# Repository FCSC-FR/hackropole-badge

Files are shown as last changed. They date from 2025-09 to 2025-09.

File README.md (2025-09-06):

# Hackropole badge

<!--
SPDX-FileCopyrightText: 2025 Hackropole
SPDX-License-Identifier: CC-BY-4.0
-->

This repository contains the source files and build instructions for the
Hackropole badge.

See [./hardware/](./hardware/) for PCB source files, and production instructions.

See [./assembly/](./assembly/README.en.md) for PCB assembly instructions
(available [in French](./assembly/README.fr.md) and [in English](./assembly/README.en.md)).

See [./firmware-wled/](./firmware-wled/README.en.md) for firmware flashing and
configuration guide (available [in French](./firmware-wled/README.fr.md) and
[in English](./firmware-wled/README.en.md)).

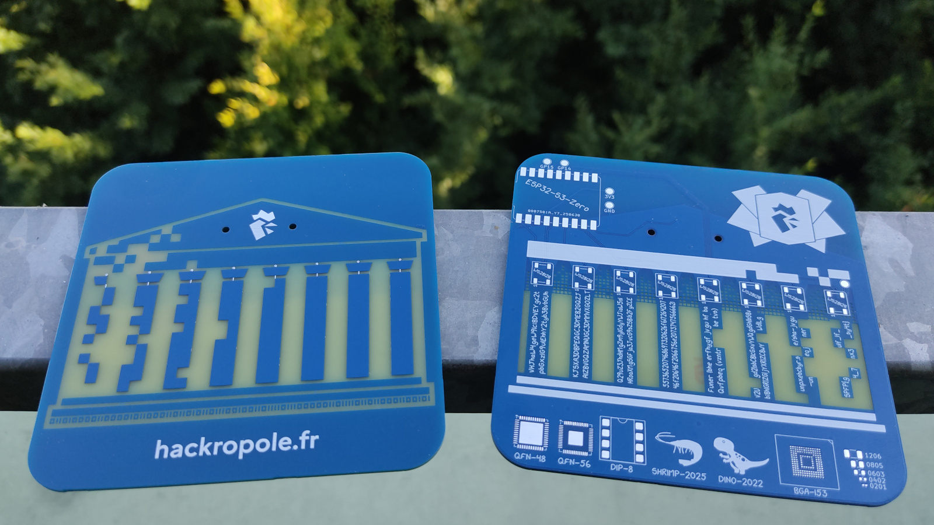
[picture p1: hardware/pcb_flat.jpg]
Pre-assembly badge


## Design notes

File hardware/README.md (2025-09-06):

# Hackropole badge

<!--
SPDX-FileCopyrightText: 2025 Hackropole
SPDX-License-Identifier: CC-BY-4.0
-->

Badge

This PCB was designed with Kicad 9.0.

## Sending the PCB to production

We recommend the following settings when sending the design files to production:

- FR-4 base material, 2 layers, 1.6mm thickness,
- Blue color (to match Hackropole colors!),
- Leadfree HASL surface finish, or ENIG (gold),
- If your fab requires to place a mark on the PCB, you may use
  "Specify Position" and update the "JLCJLCJLCJLC" text.

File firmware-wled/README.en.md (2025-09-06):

# WLED Firmware

<!--
SPDX-FileCopyrightText: 2025 Hackropole
SPDX-License-Identifier: CC-BY-4.0
-->

[WLED](https://kno.wled.ge/) is a opensource firmware to control WS2812 LEDs
with a nice Web interface and touch buttons.
WLED is free software under the European Union Public License 1.2.

## Flash firmware

To flash the firmware, you need to have `esptool` installed.
If your package distribution does not ship `esptool`, you may follow the official
instructions to install it via pip:
<https://docs.espressif.com/projects/esptool/en/release-v4/esp32/installation.html>

Connect the ESP32-S3 USB cable while pressing the boot button (marked "B") to
enter the bootloader mode.
Make sure you user can write to '/dev/ttyACM0'. Then:

```bash
esptool.py --port /dev/ttyACM0 erase_flash
esptool.py --port /dev/ttyACM0 write_flash 0x0 bootloader.bin
esptool.py --port /dev/ttyACM0 write_flash 0x8000 partitions.bin
esptool.py --port /dev/ttyACM0 write_flash 0x10000 firmware.bin
```

Then reset the board (e.g. by unplugging it).

## Build firmware from sources

If you don't trust our pre-built binaries, you may download and rebuild them
from source!

```bash
git clone https://github.com/wled/WLED
# checkout 28 Jun 2025 version, this matchs distributed pre-built binaries
git checkout cc81cc27b033b8358b4acc1f4155d51f31b83f5d
pio run -e esp32s3_4M_qspi -t upload
```

## Initial setup

After successfully flashing the firmware, you should see a new Wi-Fi network `WLED-AP`.
You may connect to this network using the following password: `wled1234`,
then you should see a web page "Welcome to WLED!".
You may press "WIFI SETTINGS" to configure now the badge as a Wi-Fi client.

## LED and buttons configuration

The Hackropole badge has:

- 8 WS2812B LED on GPIO 2
- 1 WS2812B LED on GPIO 21
- 8 capacitive touch buttons on GPIO 1, 3, 4, 5, 7, 8, 9, 10 (each pillar),
  and one on GPIO 6 (rooster's crest)
- GPIO 14 and 15 exposed on pads for user modding (e.g. for 3.3V I2C sensors,
  I2S microphone)

To configure the LED, you should go to `Config > LED Preferences`
(or `http://DEVICE_IP/settings/leds`), then in "Hardware setup / LED outputs" configure:

- Set `Length: 8`, `Data GPIO: 2`
- Press '+' and set `Length: 1`, `Data GPIO: 21`

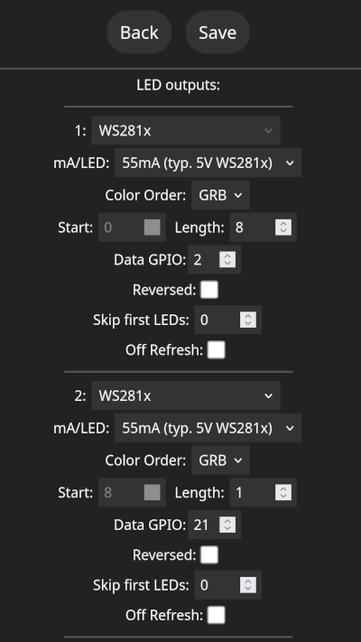
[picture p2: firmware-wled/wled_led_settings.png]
WLED LED Preferences


To configure the buttons, go to the same page (still in `LED Preferences`), and configure:

- Button 0 GPIO: 6 Touch
- Button 1 GPIO: 1 Touch
- Button 2 GPIO: 4 Touch
- Button 3 GPIO: 7 Touch

By default button 0 should toggle the light, and button 1 should cycle effects.

Due to a limitation in WLED firmare, only 4 touch buttons can be configured
at once.
However the hardware should be able to handle all 9 buttons.

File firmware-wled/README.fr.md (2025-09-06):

# Micrologiciel WLED

<!--
SPDX-FileCopyrightText: 2025 Hackropole
SPDX-License-Identifier: CC-BY-4.0
-->

[WLED](https://kno.wled.ge/) est un micrologiciel opensource permettant de
contrôler les LED WS2812 à l'aide d'une interface Web intuitive et avec des
boutons tactiles.
WLED est un logiciel libre distribué sous licence European Union Public License 1.2.

## Flasher le micrologiciel

Pour flasher le micrologiciel, vous avez besoin de l'utilitaire `esptool`.
Si votre distribution ne fournit pas `esptool`, vous pouvez suivre les
instructions officielles pour l'installer via pip :
<https://docs.espressif.com/projects/esptool/en/release-v4/esp32/installation.html>

Connectez le câble USB vers l'ESP32-S3 tout en appuyant sur le bouton de boot
(marqué « B ») pour passer en mode bootloader.
Assurez-vous que votre utilisateur peut écrire dans "/dev/ttyACM0". Ensuite :

```bash
esptool.py --port /dev/ttyACM0 erase_flash
esptool.py --port /dev/ttyACM0 write_flash 0x0 bootloader.bin
esptool.py --port /dev/ttyACM0 write_flash 0x8000 partitions.bin
esptool.py --port /dev/ttyACM0 write_flash 0x10000 firmware.bin
```

Réinitialisez ensuite la carte (par exemple en la débranchant).

## Compiler le micrologiciel à partir des sources

Si vous ne faites pas confiance à nos binaires pré-compilés, vous pouvez les
télécharger et les recompiler à partir du code source :

```bash
git clone https://github.com/wled/WLED
# checkout 28 Jun 2025 version, this matchs distributed pre-built binaries
git checkout cc81cc27b033b8358b4acc1f4155d51f31b83f5d
pio run -e esp32s3_4M_qspi -t upload
```

## Configuration initiale

Une fois le micrologiciel flashé, vous devriez voir apparaître un nouveau réseau
Wi-Fi nommé "WLED-AP".
Vous pouvez vous connecter à ce réseau à l'aide du mot de passe suivant :
"wled1234".
Vous devriez alors voir apparaître une page Web intitulée "Welcome to WLED!".
Vous pouvez appuyer sur "WIFI SETTINGS" pour configurer le badge en tant que
client Wi-Fi.

## Configuration des LED et des boutons

Le badge Hackropole dispose de :

- 8 LED WS2812B sur GPIO 2
- 1 LED WS2812B sur GPIO 21
- 8 boutons capacitifs sur les GPIO 1, 3, 4, 5, 7, 8, 9, 10 (chaque pilier) et
  un sur le GPIO 6 (crête du coq)
- GPIO 14 et 15 exposés sur des pads pour les usermods (par exemple pour des
  capteurs I2C 3,3 V, un microphone I2S)

Pour configurer la LED, rendez-vous dans `Config > LED Preferences`
(ou `http://DEVICE_IP/settings/leds`), puis dans "Hardware setup / LED outputs"
et configurez :

- Définissez `Length : 8`, `Data GPIO : 2`
- Appuyez sur '+' et définissez `Length : 1`, `Data GPIO : 21`

Préférences LED WLED

Pour configurer les boutons, allez sur la même page (toujours dans
`LED Preferences`) et configurez :

- Bouton 0 GPIO : 6 Touch
- Bouton 1 GPIO : 1 Touch
- Bouton 2 GPIO : 4 Touch
- Bouton 3 GPIO : 7 Touch

Par défaut, le bouton 0 devrait activer/désactiver la lumière et le bouton 1
devrait changer l'effet actif.

En raison d'une limitation du micrologiciel WLED, seuls 4 boutons tactiles
peuvent être configurés à la fois. Cependant, le matériel devrait pouvoir gérer
les 9 boutons.

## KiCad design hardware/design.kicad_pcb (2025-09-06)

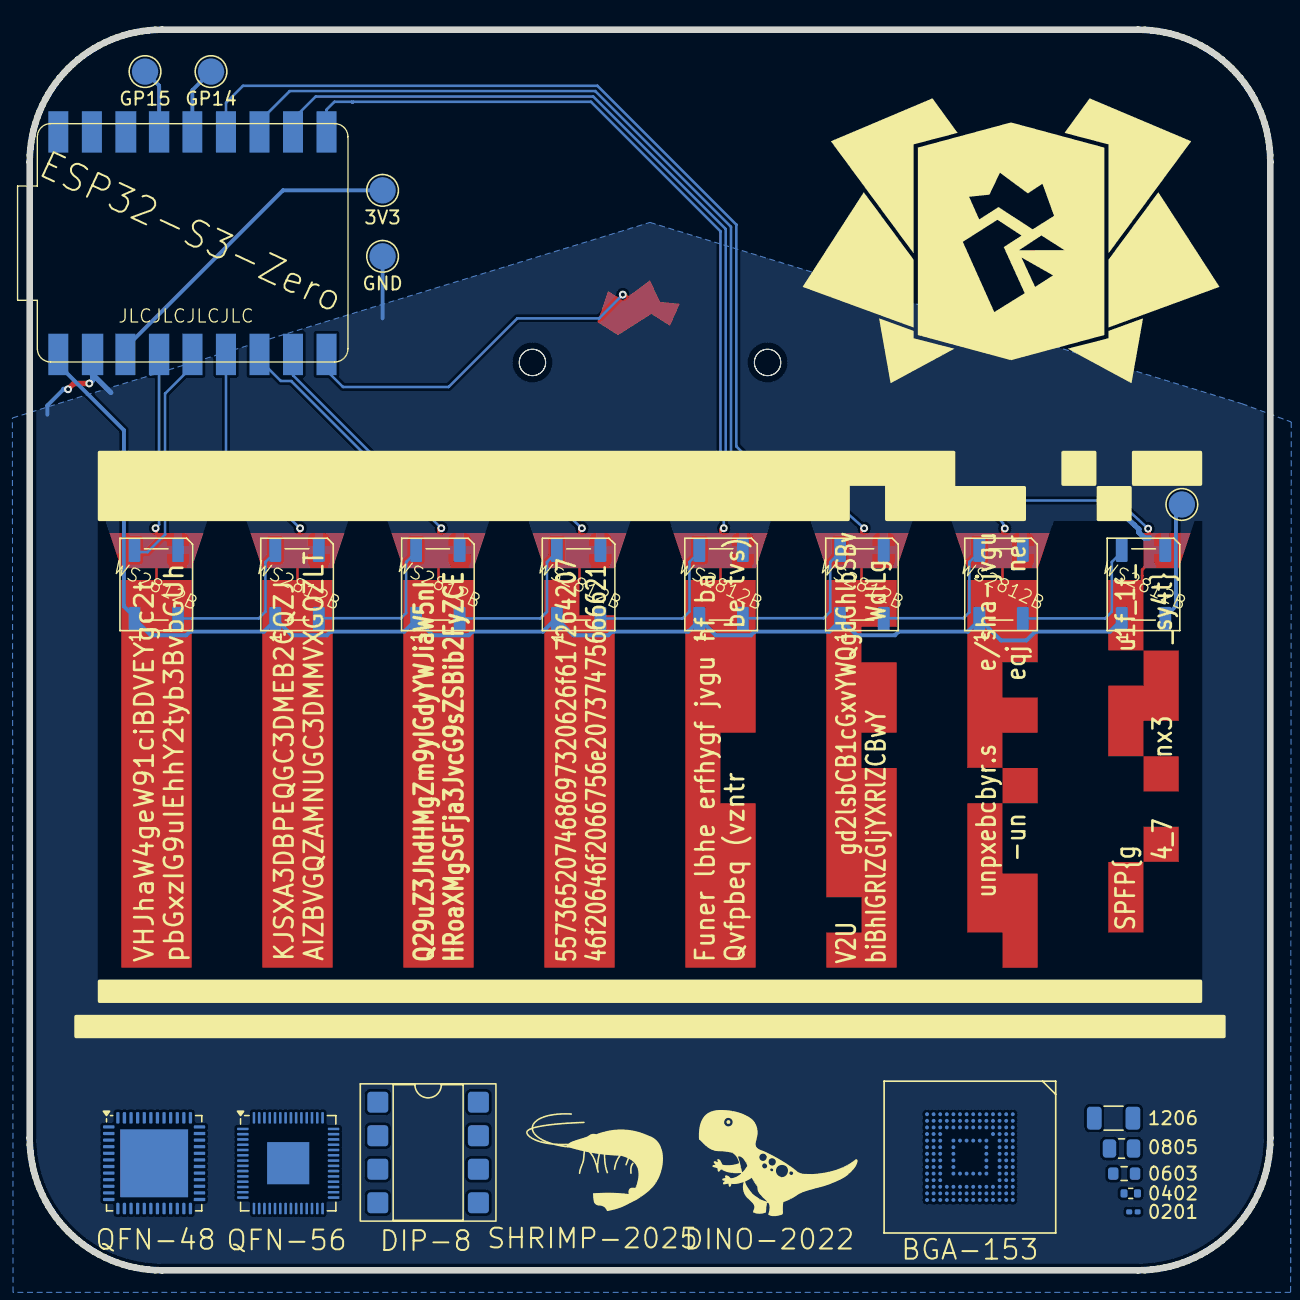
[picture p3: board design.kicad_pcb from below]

Board: 2 copper layers, 94.0 x 94.0 mm, 22 parts (22 on the bottom side), 14 nets.

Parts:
D1, D2, D3, D4, D5, D6, D7, D8: WS2812B; LED_WS2812B_PLCC4_5.0x5.0mm_P3.2mm
R1: 0201; R_0201_0603Metric
R2: 0402; R_0402_1005Metric
R3: 0603; R_0603_1608Metric
R4: 0805; R_0805_2012Metric
R5: 1206; R_1206_3216Metric
TP1: GP15; TestPoint_Pad_D2.0mm
TP2: GP14; TestPoint_Pad_D2.0mm
TP3: 3V3; TestPoint_Pad_D2.0mm
TP4: GND; TestPoint_Pad_D2.0mm
TP5: DOUT; TestPoint_Pad_D2.0mm
U1: ESP32-S3-Zero; Waveshare-ESP32-S3-Zero
U2: DIP-8; DIP-8_W7.62mm_SMDSocket_SmallPads
U3: RP2040; QFN-56-1EP_7x7mm_P0.4mm_EP3.2x3.2mm
U4: AMT49413; QFN-48-1EP_7x7mm_P0.5mm_EP5.15x5.15mm

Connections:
+3.3V: TP3.1, U1.3 (3V3(OUT))
+5V: D1.1 (VDD), D2.1 (VDD), D3.1 (VDD), D4.1 (VDD), D5.1 (VDD), D6.1 (VDD), D7.1 (VDD), D8.1 (VDD), U1.1 (VDD)
/GP14: TP2.1, U1.14 (GPIO11)
/GP15: TP1.1, U1.15 (GPIO12)
/LED_DIN: D1.4 (DIN), U1.5 (GPIO2)
/LED_DOUT: D8.2 (DOUT), TP5.1
GND: D1.3 (VSS), D2.3 (VSS), D3.3 (VSS), D4.3 (VSS), D5.3 (VSS), D6.3 (VSS), D7.3 (VSS), D8.3 (VSS), TP4.1, U1.2 (GND)
unnamed: D1.2 (DOUT), D2.4 (DIN)
unnamed: D2.2 (DOUT), D3.4 (DIN)
unnamed: D3.2 (DOUT), D4.4 (DIN)
unnamed: D4.2 (DOUT), D5.4 (DIN)
unnamed: D5.2 (DOUT), D6.4 (DIN)
unnamed: D6.2 (DOUT), D7.4 (DIN)
unnamed: D7.2 (DOUT), D8.4 (DIN)

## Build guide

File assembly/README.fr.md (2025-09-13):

# Assemblage du badge Hackropole

<!--
SPDX-FileCopyrightText: 2025 Hackropole
SPDX-License-Identifier: CC-BY-4.0
-->

Vous venez de recevoir votre tout nouveau badge Hackropole et vous souhaitez
l'assembler ? Vous pouvez suivre ce guide pour assembler le badge.

> [!WARNING]
> Le FCSC/Hackropole ne peut être tenu responsable si vous vous faites mal
> pendant le montage, cassez quelque chose ou blessez votre chat.
> Soyez prudent avec les fers à souder, ils sont chauds, émettent des fumées et
> peuvent être très dangereux s'ils sont mal utilisés !

## Composants requis

Bien que le PCB permette une certaine flexibilité de modding pour exprimer votre
créativité, nous recommandons vivement de vous procurer les éléments suivants
afin de disposer d'une base sur laquelle vous appuyer :

- **1x [ESP32-S3-Zero](https://www.waveshare.com/wiki/ESP32-S3-Zero) sans les broches pré-soudés**,
  aussi parfois appelé "ESP32-S3 Mini".
  Cette carte est disponible sur [la boutique Waveshare](https://www.waveshare.com/product/arduino/boards-kits/esp32-s3/esp32-s3-zero.htm),
  mais vous pouvez également la trouver chez d'autres revendeurs comme par exemple
  [ThePiHut](https://thepihut.com/products/esp32-s3-zero-mini-development-board),
  ou sur des marketplaces internationaux (ceux commençant par "Ali").
  Attention, **n'achetez pas les variantes "SuperMini"** car leur brochage est
  différent et ne fonctionnera pas !
- **8x WS2812B LED, au format 5050SMD**. Ces LED peuvent être achetés en grande
  quantité (100 pièces et plus) pour une somme modique dans certains magasins internationaux.
- Un fer à souder (si possible asservi en température) et un peu de fil à souder.
  Les petits fers à souder USB-C tels que [ceux pris en charge par IronOS](https://ralim.github.io/IronOS/)
  sont adaptés pour les débutants.

Composants **facultatifs** pour modifier votre carte ultérieurement et exprimer
votre créativité :

- Un tour de cou pour porter le circuit imprimé comme un badge de conférence
  (et avoir la classe !).
- Une batterie externe USB pour rendre le badge autonome.
- 2x entretoises en nylon M2 6mm (écrou, boulon et pilier hexagonal) pour
  construire une boîte-lampe avec 2 badges.
- Quelques capteurs compatibles Qwiic et un câble Qwiic à souder sur les pads
  GP14/GP15/3V3/GND. Qui a dit que votre badge ne devrait pas mesurer la
  lumière ambiante ? :D

Pour plus d'inspiration, vous pouvez consulter [la page des usermods WLED](https://github.com/wled/WLED/blob/main/usermods/readme.md).

## Assemblage de l'ESP32-S3-Zero et des LED

Commencez par nettoyer la carte, en particulier les pads sur lesquels vous allez
souder les composants.
N'utilisez pas d'eau pour le nettoyage, car elle pourrait être corrosive.
Préférez l'**alcool isopropylique**.

> [!WARNING]
> Les fumées de soudure contiennent un nombre élevé de particules.
> Vous devez toujours souder avec un extracteur de fumées en marche,
ou au moins dans un endroit très ventilé.

Soudez l'ESP32-S3-Zero en mettant un peu de soudure sur la broche 7, en vous
assurant que le composant est correctement placé, puis en mettant de la soudure
sur la broche opposée (5V) pour verrouiller la position. Commencez ensuite à
souder toutes les broches restantes une par une.
Lorsque le résultat obtenu est satisfaisant, nettoyez les résidus de flux
restant sur le circuit imprimé.

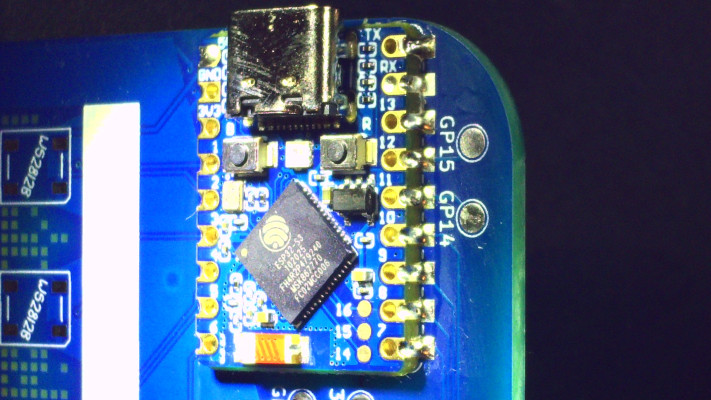
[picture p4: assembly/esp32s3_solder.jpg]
ESP32-S3-Zero soudé


Utilisez une technique similaire pour chaque LED WS2812B, mais diminuez
légèrement la température du fer à souder, car le plastique des LED peut
facilement fondre.

Vous pouvez également vous référer à la vidéo suivante qui montre le processus
de soudage : [esp32s3_soldering.webm](./esp32s3_soldering.webm)

## Après avoir assemblé la carte

Pour vérifier si la carte fonctionne, vous pouvez flasher le micrologiciel WLED.
Référez-vous à [../firmware-wled/](../firmware-wled/README.fr.md) pour flasher
et de configurer le micrologiciel.

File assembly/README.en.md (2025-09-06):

# Hackropole badge assembly

<!--
SPDX-FileCopyrightText: 2025 Hackropole
SPDX-License-Identifier: CC-BY-4.0
-->

You just got your brand-new Hackropole badge and are looking to assemble it?
You may follow this guide to get a working board.

> [!WARNING]
> The FCSC/Hackropole staff may not be held responsible if you hurt yourself
> during the assembly, break something, or hurt your cat.
> Please be careful with soldering irons, they are hot, emit fumes and can
> become quite dangerous if misused!

## Required components

Although the PCB allows for user modding and a lot of creativity, we highly
recommend getting the following to have a baseline to build upon:

- **1x [ESP32-S3-Zero](https://www.waveshare.com/wiki/ESP32-S3-Zero) without pin headers**,
  also sometimes called "ESP32-S3 Mini".
  It is available on [Waveshare shop](https://www.waveshare.com/product/arduino/boards-kits/esp32-s3/esp32-s3-zero.htm),
  but you may also find it on other suppliers such as
  [ThePiHut](https://thepihut.com/products/esp32-s3-zero-mini-development-board),
  or on some international marketplaces (those starting with "Ali").
  Don't buy "SuperMini" variants, as their pinout is different and won't work!
- **8x WS2812B LED, in 5050SMD packages**. They can be bought in large
  quantities (100pcs+) for a small fee at some international shops.
- A soldering iron (better if temperature controlled) and some solder wire.
  Small USB-C soldering irons such as [those supported by IronOS](https://ralim.github.io/IronOS/)
  are great for beginners.

**Optional** components for modding your board later and to unleash your creativity:

- Some neckband to hold the PCB as a conference badge (and look extra cool!).
- A USB PowerBank to keep the badge powered even far away from a power outlet.
- 2x M2 6mm nylon standoff (nut, bolt and hex pillar), to build a box lamp with
  2 badges.
- Some Qwiic-compatible sensors, and a Qwiic cable to solder on GP14/GP15/3V3/GND
  pads. Who said that your badge shouldn't have an ambient light sensor? :D

For more inspiration, you may take a look at
[WLED usermods](https://github.com/wled/WLED/blob/main/usermods/readme.md).

## ESP32-S3-Zero and LED assembly

Starts by cleaning the board, especially the pads on which you are going to
solder components.
Don't use water to clean as it might be corrosive, prefer **isopropyl alcool**.

> [!WARNING]
> Solder fumes contain a high number of particules.
> You should always solder with a fume extractor running, or at least in a
> highly-ventilated area.

Solder the ESP32-S3-Zero by putting some solder on pin 7, making sure the
component is correctly placed, then putting solder on the opposite pin (5V)
to lock the position. Then start soldering all pins one by one.
When you are happy about how the soldered pins turned out, clean the remaining
flux on the PCB.

ESP32-S3-Zero soldered

Use the same technique for each WS2812B LED, but lower a bit the solder iron
temperature as the LED plastic can easily melt.

You may also refer to the following video showing the soldering process:
[esp32s3_soldering.webm](./esp32s3_soldering.webm)

## After assembling the board

To test if the board is working, you may flash WLED firmware.
See [../firmware-wled/](../firmware-wled/README.en.md) for firmware flashing
and configuration guide.

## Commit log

2025-09-06 Update assembly instructions
2025-09-06 Minor pcb changes
    [design.kicad_pcb]
2025-09-06 Improve assembly instructions
2025-09-13 assembly: fix typo in README
